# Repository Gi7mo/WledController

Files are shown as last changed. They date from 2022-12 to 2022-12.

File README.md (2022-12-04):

# WLED Controller for 5V LED Strips

*e.g. ws2812b, and only tested with them*

The Power supply is a 100-240VAC one and  rated at 5v 4A, don't exceed the power of the supply. Use e.g. the [WLED power calculator](https://wled-calculator.github.io/)

**As i live in germany, the pcb is only tested with 230V AC, if you supply any other voltage, be warned!**

*It can go up in flames, explode or kill you. It's main power!*

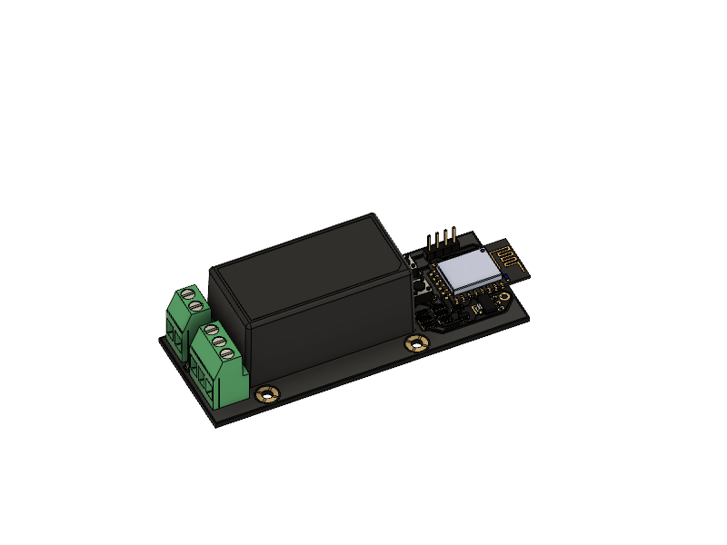
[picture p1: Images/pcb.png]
pcb
- 

**BOM**
|Reference |Quantity|Value |LCSC |ALI |
|---|---|---|---|---|
|C1 C2 |2 |C |C107172 |[Link](https://s.click.aliexpress.com/e/_DkweKyn)|
|J1 |1 |Conn_01x02_Male |C475092 |[Link](https://s.click.aliexpress.com/e/_DC1TC2L)|
|J2 |1 |Conn_01x03_Male |C475093 |[Link](https://s.click.aliexpress.com/e/_DC1TC2L)|
|J3 |1 |Conn_01x04_Male |C2691448|[Link](https://s.click.aliexpress.com/e/_DDO0FkL)|
|Q1 |1 |BSS138 |C52895  |[Link](https://s.click.aliexpress.com/e/_DF4Oc0f)|
|R1 R2 R3 R4 R5 R6 R7 |7 |10K |C144471 |[Link](https://s.click.aliexpress.com/e/_Ddns0gR)|
|SW1 |1 |SW_FLASH |C393938 |[Link](https://s.click.aliexpress.com/e/_DdksuhH)|
|SW2 |1 |SW_RESET |C393938 |[Link](https://s.click.aliexpress.com/e/_DdksuhH)|
|U2 |1 |AMS1117-3.3 |C5199435|[Link](https://s.click.aliexpress.com/e/_DF2uDUr)|
|U3 |1 |ESP8266-12E/ESP-12E |C82891  |[Link](https://s.click.aliexpress.com/e/_DlO99yR)|
|M3 Threaded Insert |2 |M3x5x4 | |[Link](https://s.click.aliexpress.com/e/_DEReEY7)|
|ISO 7380-1 Screws |2 |M3x6 | |[Link](https://s.click.aliexpress.com/e/_Dd6fzUn)|
|U1 |1 |[Meanwell_MPM-20-5](https://www.meanwell-web.com/en-gb/ac-dc-single-output-medical-encapsulated-power-mpm--20--5)  | | |
|USB to Serial Converter |OPTIONAL|FT232 | |[Link](https://s.click.aliexpress.com/e/_DD2GD3H)|

For the Cable Holes i added some [Rubber Cable Rings](https://www.ebay.de/itm/202766961119) with 6mm inner diameter

**Assembly**
- Order the pcb at e.g. [pcbway](https://www.pcbway.com/project/shareproject/WLED_Controller_for_5V_LED_Strips_270c2944.html) or [jlcpcb](https://jlcpcb.com/)
- While you wait, Print the casing
- Assemble the PCB
- use a soldering iron to mount your threaded inserts in the case
- mount the rubber rings, if you brought them
- Check your usb 2 serial converter that it is set to 3.3V (any other voltage will damage the esp8266)
- use the pcb pin headers to wire up the PCB with the usb 2 serial converter
```
┌────────────────────┐
│  VCC  GND  TX  RX  │
│   │    │   │ ┌──┘  │
│   │    │   └─┼──┐  │
│   │    │   ┌─┘  │  │
│   ▼    ▼   ▼    ▼  │
│  VCC  GND  TX  RX  │
└────────────────────┘
```
- while plugging in your usb2searial conveerter, hold down the FLASH button of the pcb
- go to the [WLED web installer](https://install.wled.me/) and flash your board
- setup wifi for your board
- go to the configuration website of your board, select the led setup, the output pin is **GPIO 12**
- now pull your wires through the holes in the case, wire them up to the screw terminals
- put the pcb into the case and put the lid on it

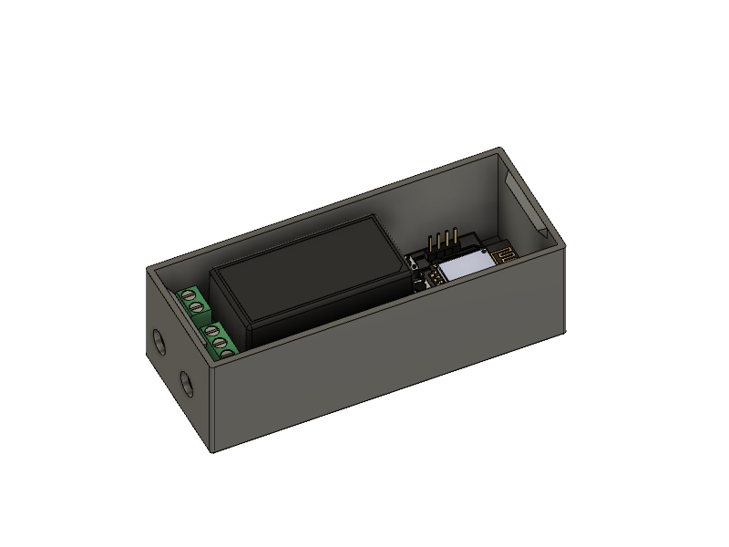
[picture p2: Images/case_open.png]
case_open
- 
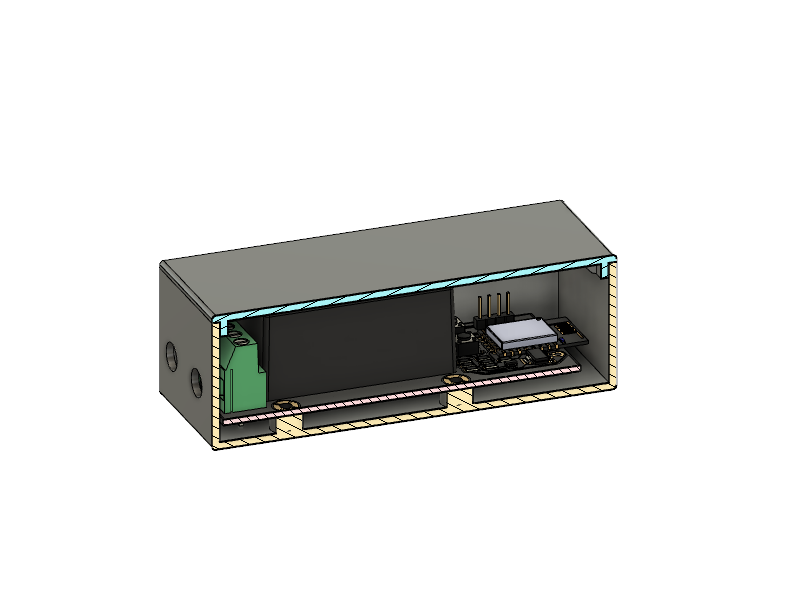
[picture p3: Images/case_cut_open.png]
case_cut
- 

## Notes
- You can contact me via Discord "Gi7mo!#4618"
- This readme file contains Amazon Associate, Aliexpress affiliate, PCBWay affiliate links. I make a comission on qualifying purchases.
- This project does not come with any warranty, if you choose to build/use one, you are doing this at your own risk!
- Be Aware, it can go up in flames, explode, harm you or kill you. Mains power is dangerous!

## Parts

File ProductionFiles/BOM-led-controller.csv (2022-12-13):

Comment | Designator | Footprint | LCSC
C | C1,C2 | C_1206_3216Metric | C107172
10K | R1,R2,R3,R4,R5,R6,R7 | R_1206_3216Metric | C144471
Conn_01x04_Male | J3 | PinHeader_1x04_P2.54mm_Vertical | C2691448
FLASH | SW1,SW2 | SW_PUSH_6mm | C393938
Conn_01x02_Male | J1 | TerminalBlock_Phoenix_MKDS-3-2-5.08_1x02_P5.08mm_Horizontal | C475092
Conn_01x03_Male | J2 | TerminalBlock_Phoenix_MKDS-3-3-5.08_1x03_P5.08mm_Horizontal | C475093
AMS1117-3.3 | U2 | SOT-223-3_TabPin2 | C5199435
BSS138 | Q1 | SOT-23 | C52895
ESP8266-12E/ESP-12E | U3 | XCVR_ESP8266-12E_ESP-12E | C82891

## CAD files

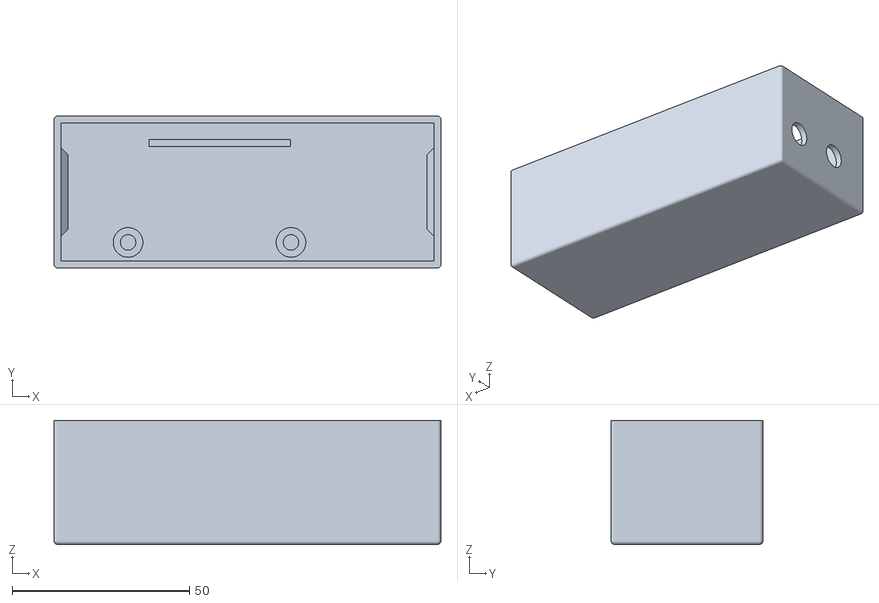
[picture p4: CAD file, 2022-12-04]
STL/case.stl
109.2 x 42.8 x 35.0

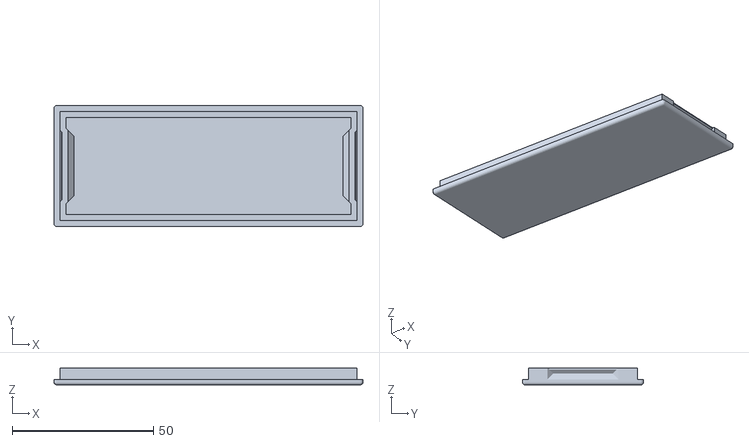
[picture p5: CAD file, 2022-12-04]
STL/cover.stl
109.2 x 42.8 x 6.00

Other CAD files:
CAD/case.f3z

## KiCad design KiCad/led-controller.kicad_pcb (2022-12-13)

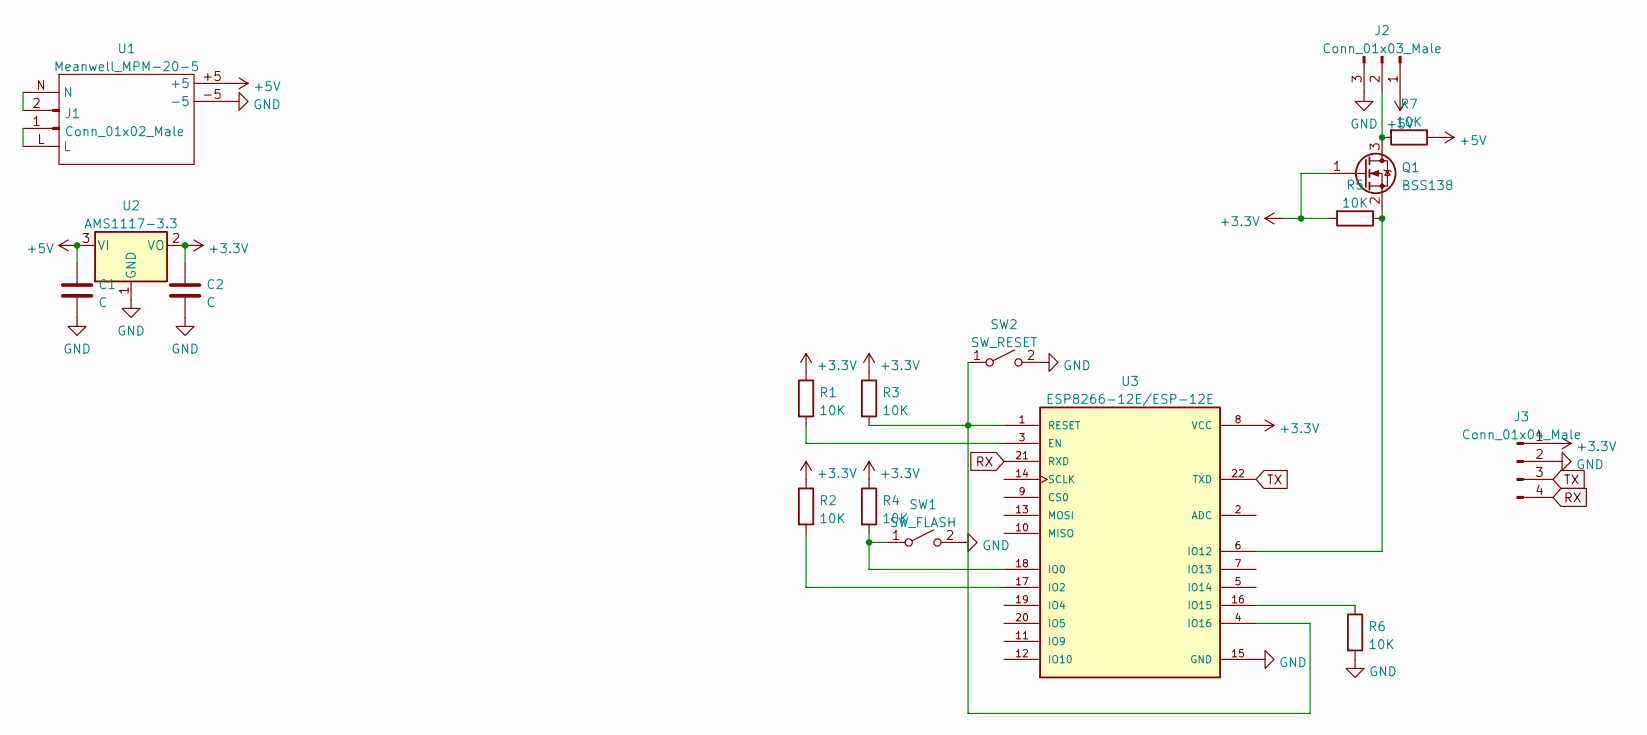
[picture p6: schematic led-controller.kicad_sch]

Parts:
C1, C2: C; C_1206_3216Metric; LCSC C107172
J1: Conn_01x02_Male; TerminalBlock_Phoenix_MKDS-3-2-5.08_1x02_P5.08mm_Horizontal; LCSC C475092
J2: Conn_01x03_Male; TerminalBlock_Phoenix_MKDS-3-3-5.08_1x03_P5.08mm_Horizontal; LCSC C475093
J3: Conn_01x04_Male; PinHeader_1x04_P2.54mm_Vertical; LCSC C2691448
Q1: BSS138; SOT-23; LCSC C52895
R1, R2, R3, R4, R5, R6, R7: 10K; R_1206_3216Metric; LCSC C144471
SW1: SW_FLASH; SW_PUSH_6mm; LCSC C393938
SW2: SW_RESET; SW_PUSH_6mm; LCSC C393938
U1: Meanwell_MPM-20-5; Meanwell MPM-20-5
U2: AMS1117-3.3; SOT-223-3_TabPin2; LCSC C5199435
U3: ESP8266-12E/ESP-12E; XCVR_ESP8266-12E/ESP-12E; LCSC C82891

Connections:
+3V3: C2.1, J3.1, Q1.1 (G), R1.1, R2.1, R3.1, R4.1, R5.2, U2.2 (VO), U3.8 (VCC)
+5V: C1.1, J2.1, R7.1, U1.+5, U2.3 (VI)
GND: C1.2, C2.2, J2.3, J3.2, R6.2, SW1.2 (B), SW2.2 (B), U1.-5, U2.1 (GND), U3.15 (GND); also elsewhere on the board
unnamed: J1.1, U1.L
unnamed: J1.2, U1.N
unnamed: J2.2, Q1.3 (D), R7.2
unnamed: Q1.2 (S), R5.1, U3.6 (IO12)
unnamed: R1.2, U3.3 (EN)
unnamed: R2.2, U3.17 (IO2)
unnamed: R3.2, SW2.1 (A), U3.1 (RESET), U3.4 (IO16)
unnamed: R4.2, SW1.1 (A), U3.18 (IO0)
unnamed: R6.1, U3.16 (IO15)
RX: J3.4, U3.21 (RXD)
TX: J3.3, U3.22 (TXD)

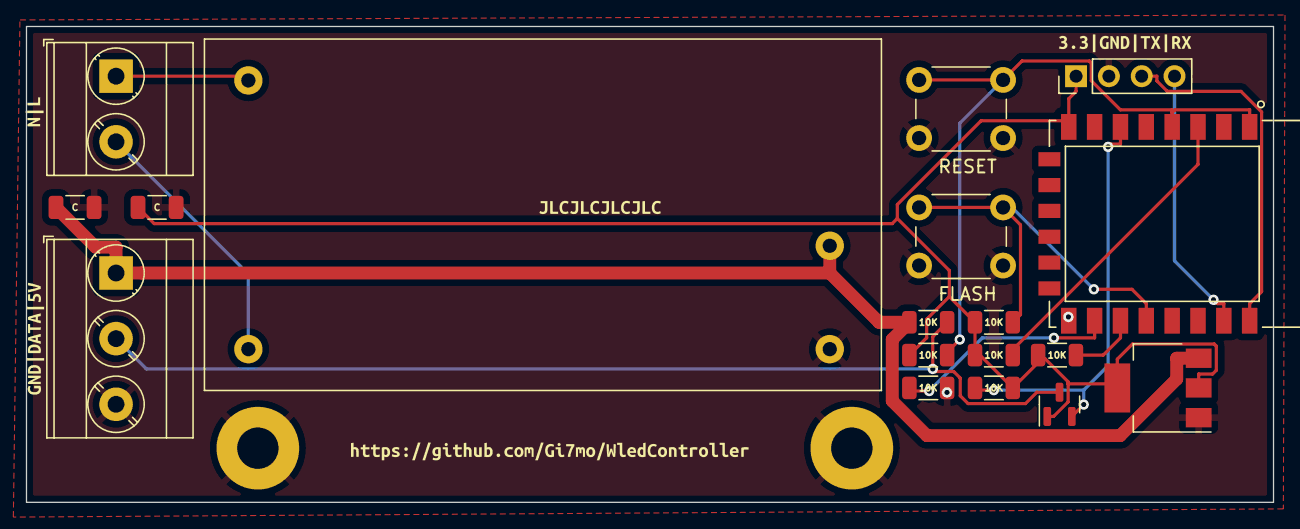
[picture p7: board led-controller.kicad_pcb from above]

Board: 2 copper layers, 96.5 x 36.8 mm, 24 parts (0 on the bottom side), 14 nets.

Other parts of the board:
hole2: MountingHole_3.2mm_M3_Pad
kibuzzard-638B31F4: G***; kibuzzard-638B31F4
kibuzzard-638B47A7: G***; kibuzzard-638B47A7
kibuzzard-63717C47: G***; kibuzzard-63717C47
kibuzzard-63717C63: G***; kibuzzard-63717C63
kibuzzard-63717D24: G***; kibuzzard-63717D24

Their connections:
GND: hole2.1; also elsewhere on the board
